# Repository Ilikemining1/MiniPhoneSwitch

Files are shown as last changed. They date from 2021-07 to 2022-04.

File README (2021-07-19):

The goal of this project is to build an analog phone switch supporting up to 8 stations and 2 analog trunks.  The switching itself is to be electromechanical in nature, but the control of the switching process and monitoring of lines will be controlled with a microcontroller.  This switch will be designed to be as modular as possible, as with the PCB manufacturing, it’s common to get multiple boards for your money, making it ideal that many of the boards are identical.

PCB Files are from KiCad, and simulation files are for LTSpice.

Simulation models are property of their respective companies.

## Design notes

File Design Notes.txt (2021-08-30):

Electronic Controlled Electromechanical Switch:
	Trunks:
		0-2 POTS trunk lines
		Programmable extension ringing
	Stations:
		0-8 Analog stations, each with programmable DNs.  
		DTMF and Pulse Support
		Properish full ring voltage, 90v RMS 20Hz Sine
	Tone Banks:
		2 tone banks, need at least one for each internal voice bus
		Produce call progress tones and decode DTMF
		Separate tone buses
	Internal Buses:
		2 internal voice paths, allowing for two simulaneous calls with any number of stations attached (multi-way calling)
		Can be used for internal calls or connected to a free analog trunk to place an outgoing call
		2 tone buses individually selectable.
	Electrical Parameters:
		Ring Generator:
			~1.2VA per 1 REN (13mA @ 90Vrms)
			Dividing active time can effectively triple REN capability of tranformer
			6 VA transformer: 5 REN no time division, effectively 15 REN with division
			Match amp wattage out approximately with transformer VA
			Transformer: FS28-200-C2 https://www.mouser.com/datasheet/2/410/FS28_200_C2-781258.pdf
			Amp: TPA3144D2 https://www.ti.com/lit/ds/symlink/tpa3144d2.pdf
		Station Cards:
			Gyrators to provide balaced line
			Ring / Voice Relay
			On-Station-Card Routing for modular design and cost savings
			Hook Detection:
				Optocoupler feeds schmitt trigger, uses software filtering to ignore ringing.
				Schmitt Trigger: NL17SZ14 https://www.mouser.com/datasheet/2/308/1/NL17SZ14_D-2318143.pdf
				Optocoupler: TCMD1000 https://www.mouser.com/datasheet/2/427/tcmd1000-1767230.pdf
			Gyrators:
				NPN: PHPT61003NY https://www.mouser.com/datasheet/2/916/PHPT61003NY-1320466.pdf
				PNP: PHPT61003PY https://www.mouser.com/datasheet/2/916/PHPT61003PY-1599682.pdf
			Connector: RJE0112001 https://cdn.amphenol-icc.com/media/wysiwyg/files/drawing/rje01x2001.pdf
			Switching Fabric:
				Relay options: EC2-5NU https://www.mouser.com/datasheet/2/212/1/KEM_R7002_EC2_EE2-1104574.pdf
				Relay Driver FET: XP231N02013R-G https://www.torexsemi.com/file/XP231N02013R/XP231N02013R.pdf
			Protection:
				Current Limit Zeners: BZX84-C9V1 https://www.mouser.com/datasheet/2/916/BZX84_SER-1319896.pdf
				Fuse (100mA slow blo): 0034.6605 https://www.mouser.com/datasheet/2/358/typ_MST_250-1888842.pdf
		Tone Banks:
			DTMF Decoder: MT8870 https://www.microsemi.com/document-portal/doc_view/127041-mt8870d-datasheet-oct2006
			Tone Generator:
				4 Wien Bridge Oscillators, 350Hz, 440Hz, 480Hz, and 620Hz
				74HC4316 to mix frequencies https://www.mouser.com/datasheet/2/916/74HC_HCT4316-1319536.pdf
				TL074, TL071 OP Amp https://www.ti.com/lit/ds/symlink/tl071h.pdf
		Microcontroller:
			Pin requirements:
				Trunks:
					2 Ring Sense (Input) (Interrupt)
					2 Hook Status (Input) (Interrupt)
					6 Trunk Routing (Output)
					2 Trunk Module Detect (Input)
				Stations:
					8 Ring Enable (Output)
					8 Hook Detect / Dial Pulse (Input) (Interrupt)
					24 Call Routing (Output)
					8 Station Module Detect (Input)
					1 Ring Gen Enable
				Tone Banks:
					8 DTMF Decoder Sense (Input)
					2 Digits Ready Sense (Input) (Interrupt)
					8 Tone Select (Output)
				Other:
					SPI:
						4 CS Pins (Output)
				Total: 32 Inputs (14 Interrupts), 51 Outputs, Total 83 GPIO
				This is an estimate and will likely change with time and the design.  
				IO Expanders: XRA1403IG24TR-F https://www.mouser.com/datasheet/2/146/XRA1403_100_092011-1889074.pdf
		Power Supply:
			-48v supply for battery voltage
			12v supply for everything else, used to produce 5v and 3.3v rails
			Additional dual +-5v for tone generator opamps
			PDME1-S12-D5-S https://www.mouser.com/datasheet/2/670/pdme1_s-1595987.pdf
			OKL-T/1-W12N-C https://www.mouser.com/datasheet/2/281/1/okl_t1_w12-1847213.pdf
			PMV65XP https://www.mouser.com/datasheet/2/916/PMV65XP-1600247.pdf

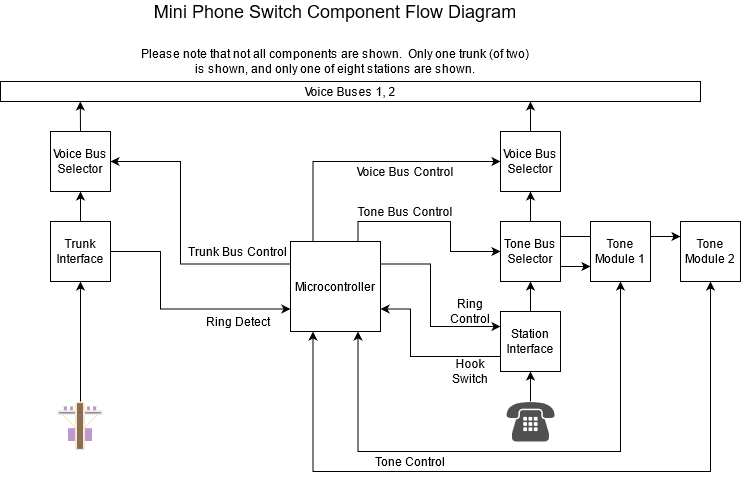
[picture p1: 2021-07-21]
Phone Switch.png

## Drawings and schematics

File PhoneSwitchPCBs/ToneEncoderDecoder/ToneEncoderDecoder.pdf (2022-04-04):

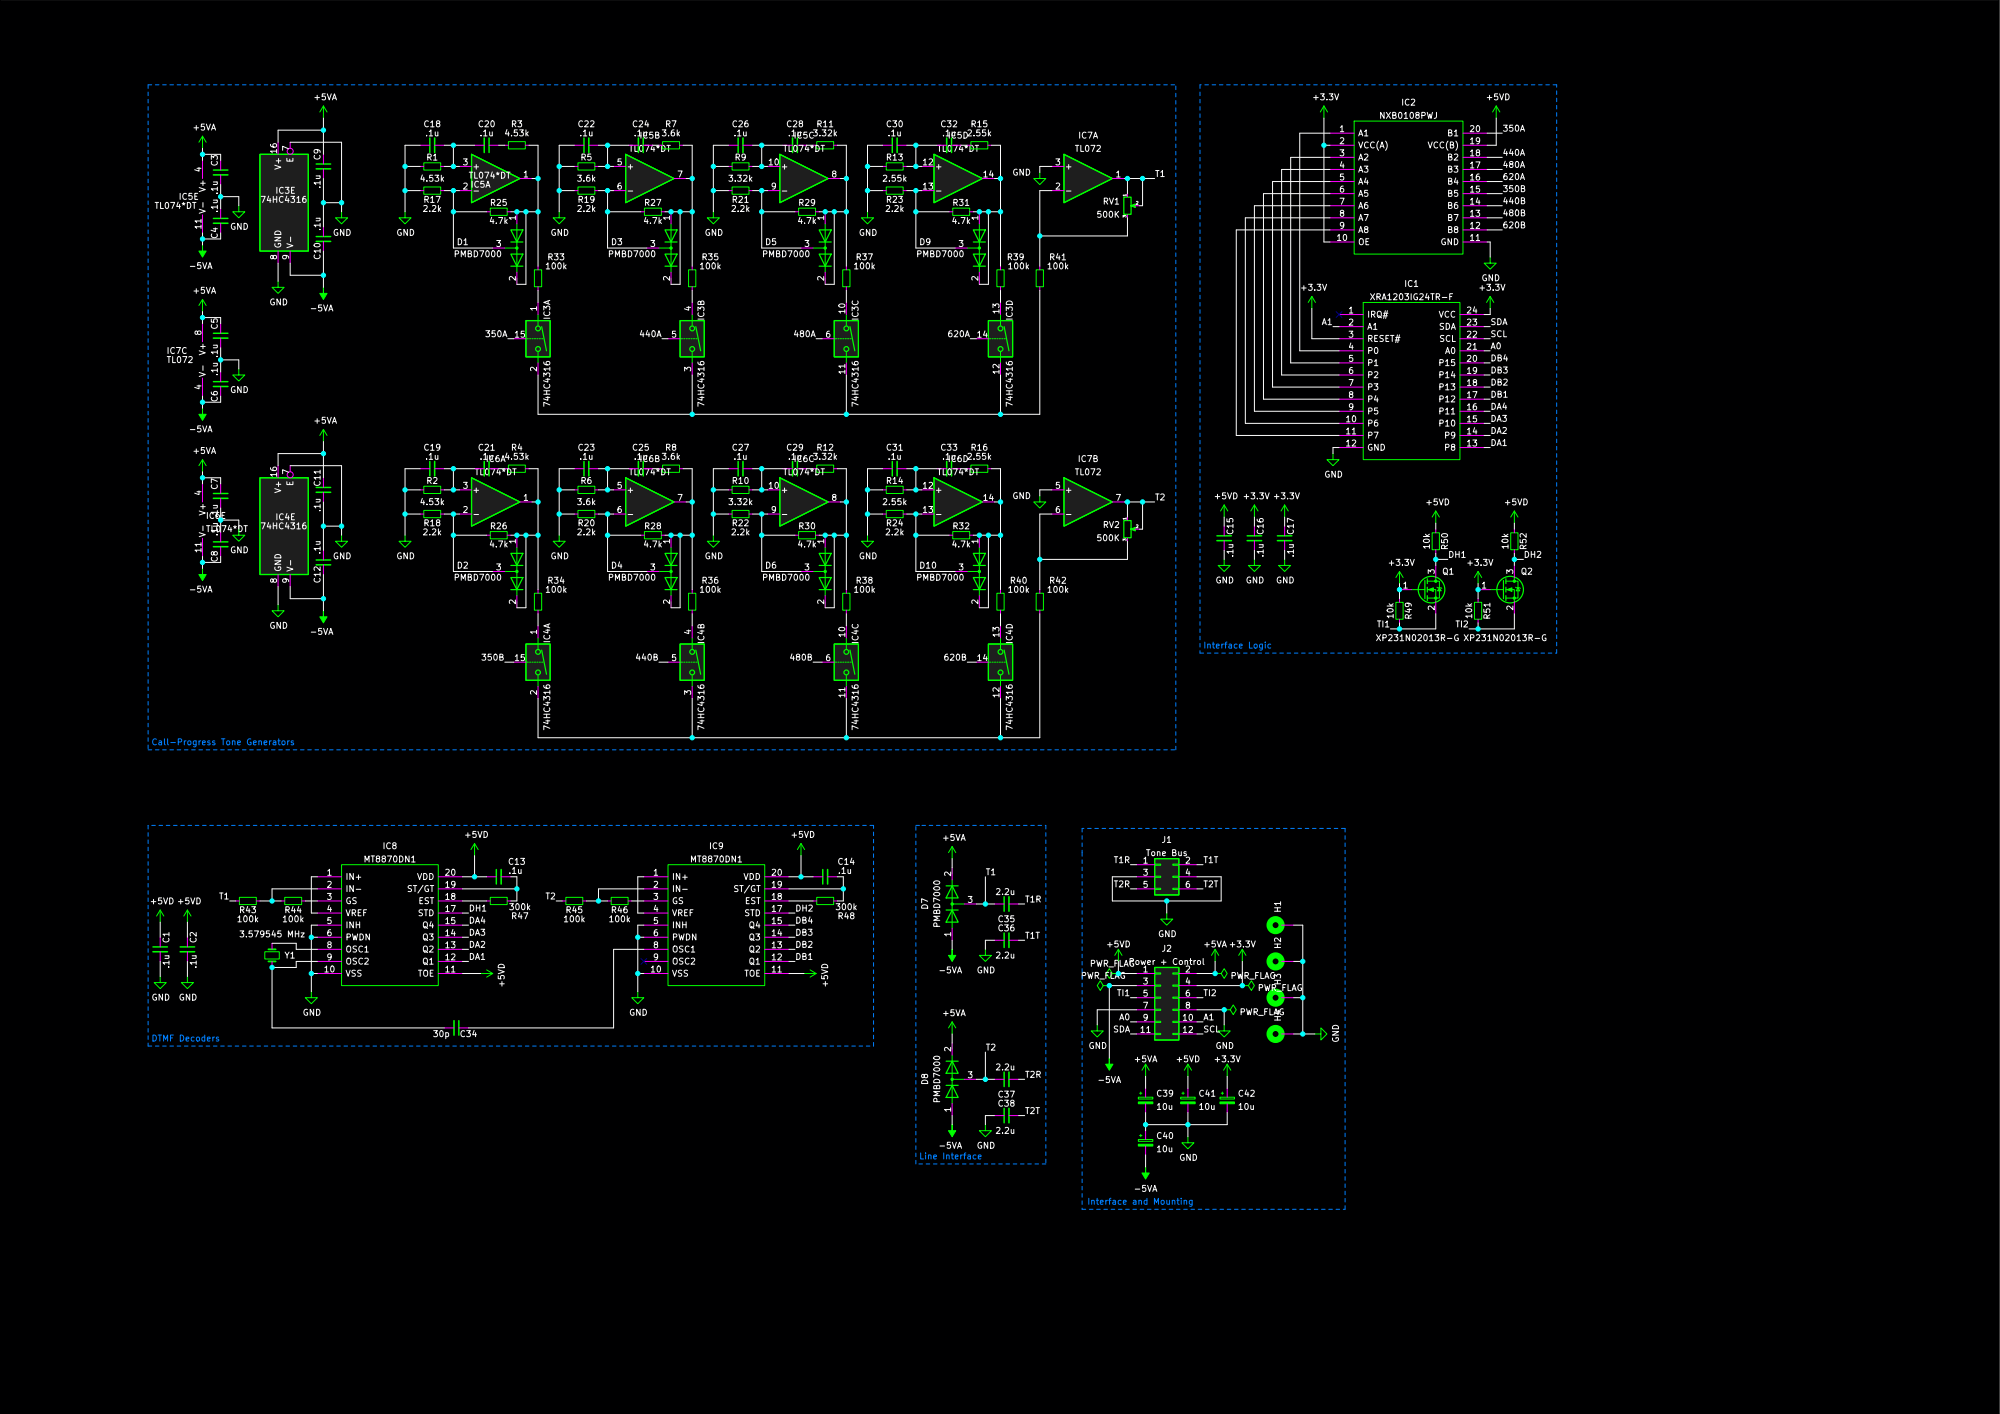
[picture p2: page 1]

Interface Logic DTMF Decoders

Line Interface Call-Progress Tone Generators

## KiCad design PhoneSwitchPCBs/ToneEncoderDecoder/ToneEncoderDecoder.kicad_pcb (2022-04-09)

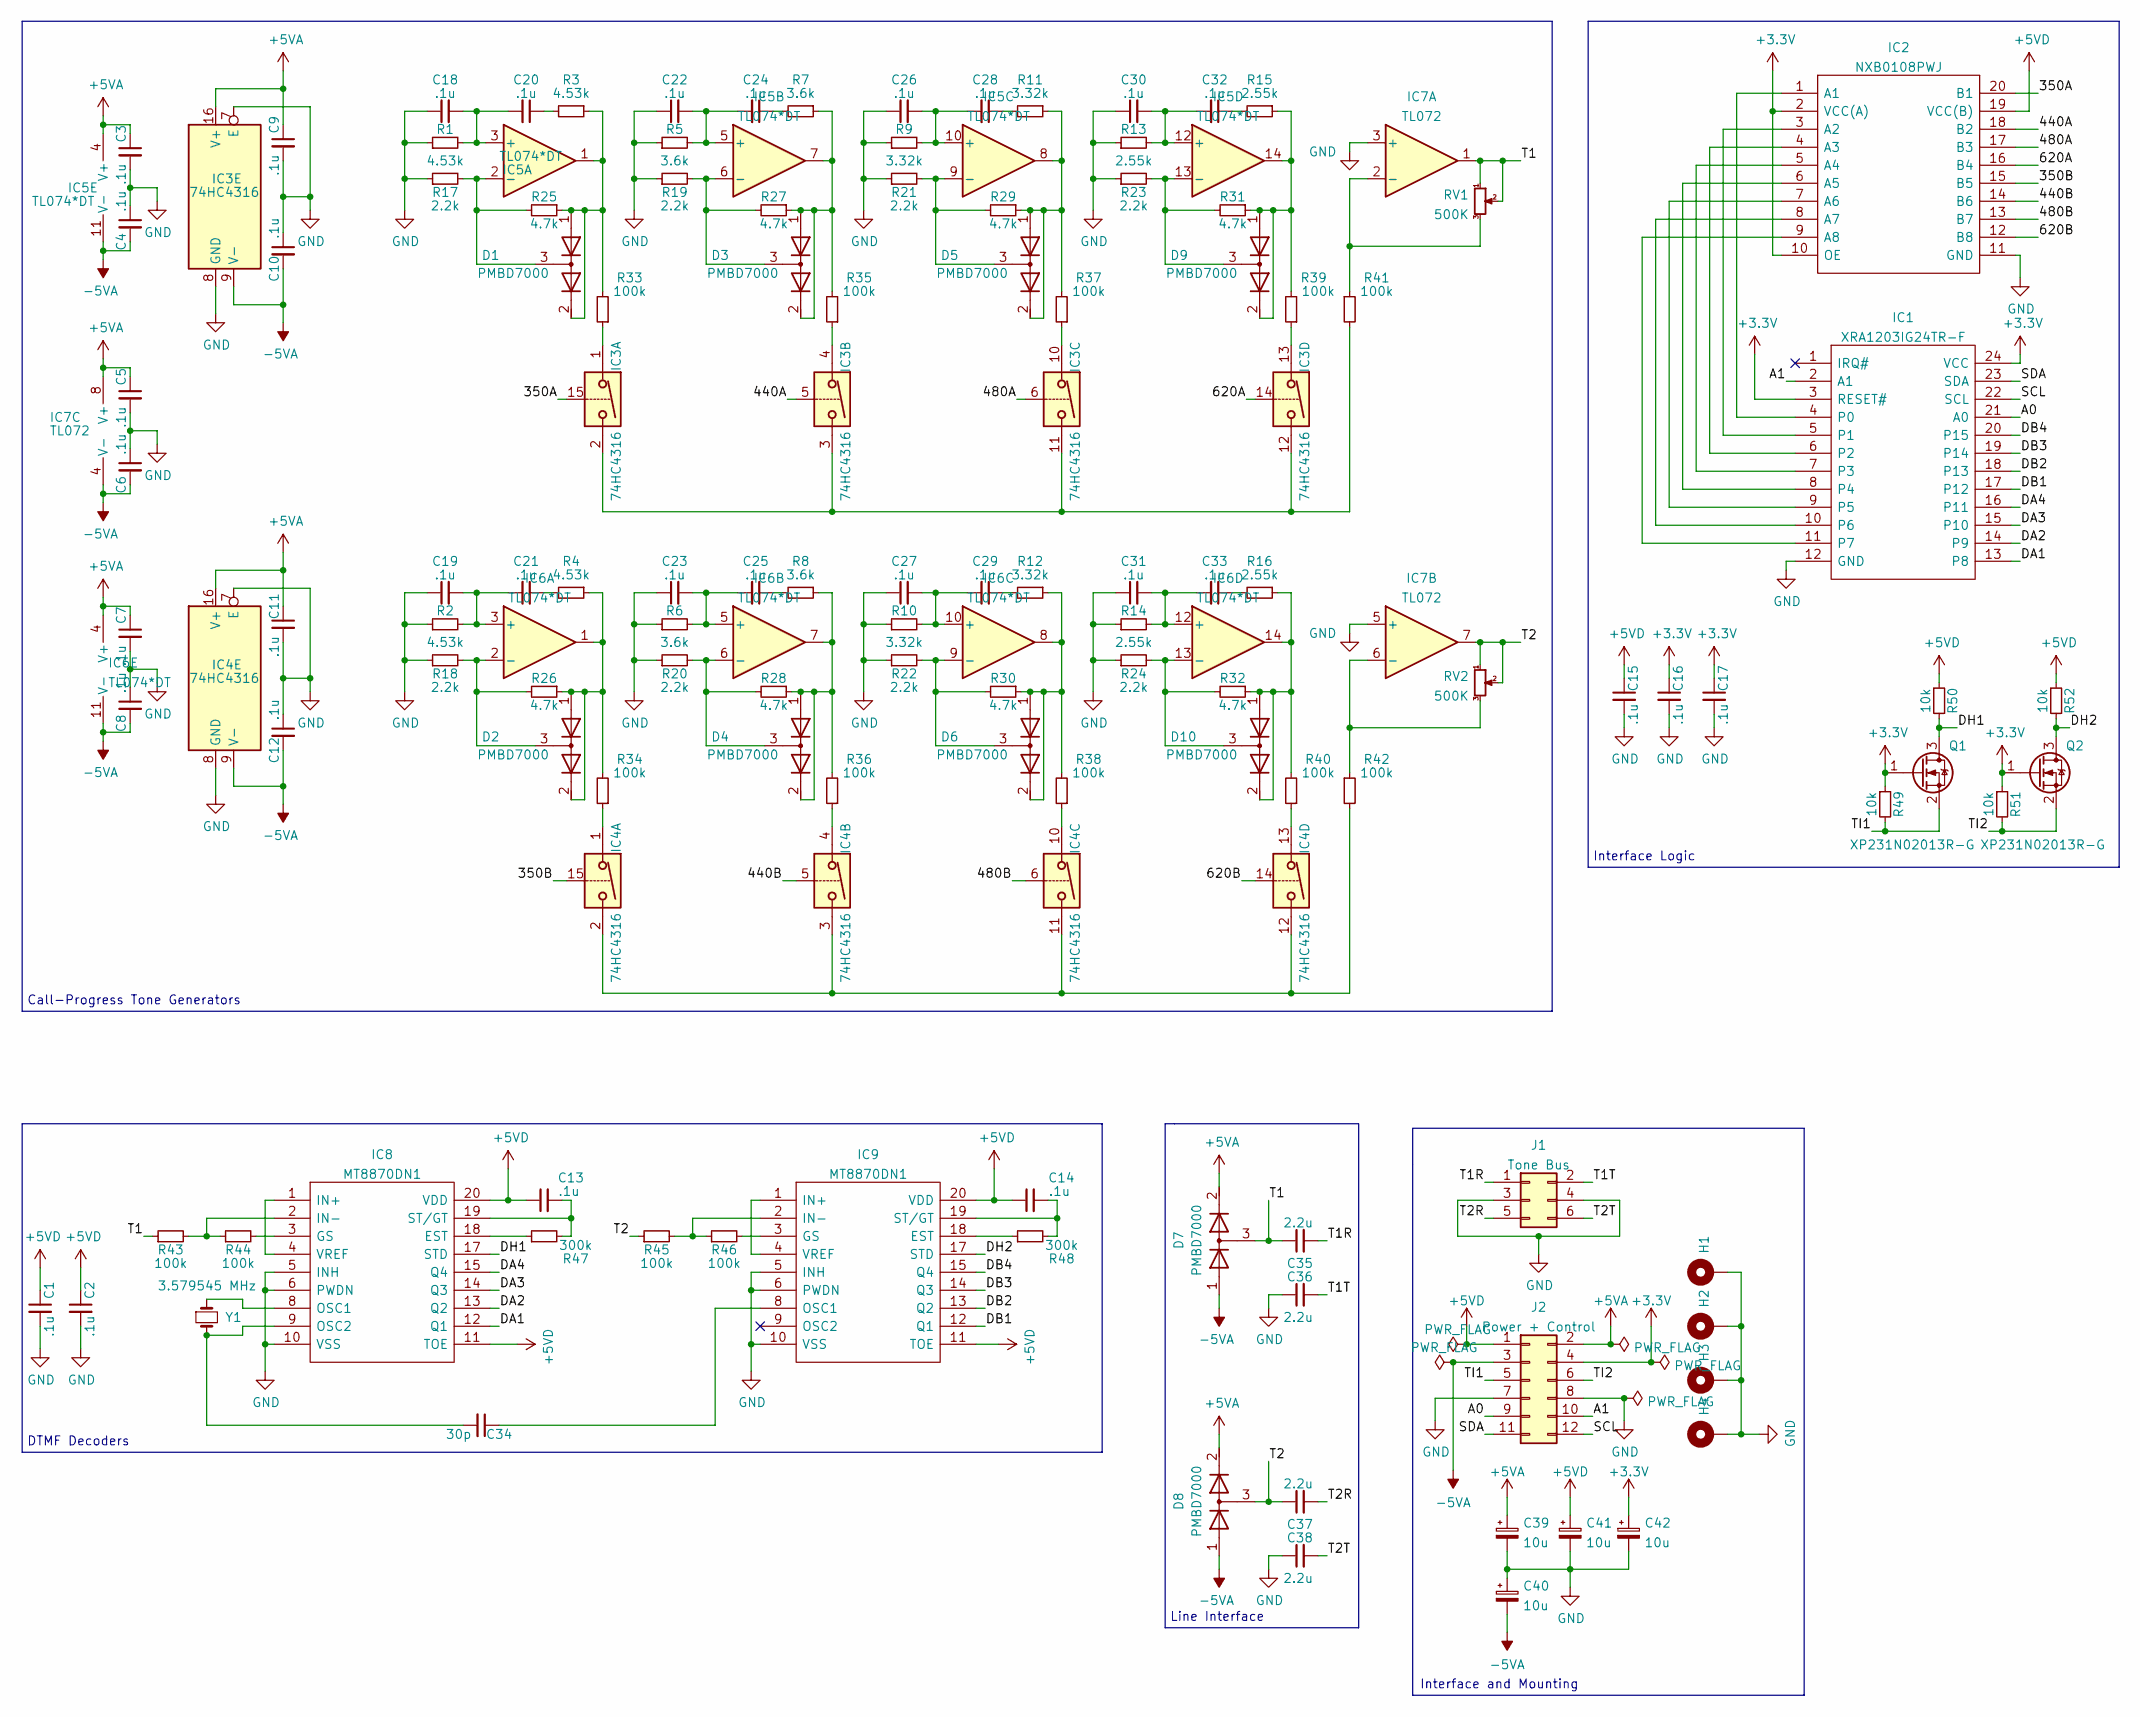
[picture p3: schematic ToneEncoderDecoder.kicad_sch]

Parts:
C1, C2, C3, C4, C5, C6, C7, C8, C9, C10, C11, C12, C13, C14, C15, C16, C17: .1u; C_0603_1608Metric_Pad1.08x0.95mm_HandSolder
C18, C19, C20, C21, C22, C23, C24, C25, C26, C27, C28, C29, C30, C31, C32, C33: .1u; C_1206_3216Metric_Pad1.33x1.80mm_HandSolder
C34: 30p; C_0603_1608Metric_Pad1.08x0.95mm_HandSolder
C35, C36, C37, C38: 2.2u; C_Radial_D5.0mm_H11.0mm_P2.00mm
C39, C40, C41, C42: 10u; C_0805_2012Metric_Pad1.18x1.45mm_HandSolder
D1, D2, D3, D4, D5, D6, D7, D8, D9, D10: PMBD7000; SOT-23
H1, H2, H3, H4: M3; MountingHole_3.2mm_M3_Pad
IC1: XRA1203IG24TR-F; TSSOP-24_4.4x7.8mm_P0.65mm
IC2: NXB0108PWJ; TSSOP-20_4.4x6.5mm_P0.65mm
IC3, IC4: 74HC4316; TSSOP-16_4.4x5mm_P0.65mm
IC5, IC6: TL074*DT; SOIC-14_3.9x8.7mm_P1.27mm
IC7: TL072; SOIC-8_3.9x4.9mm_P1.27mm
IC8, IC9: MT8870DN1; SSOP-20_5.3x7.2mm_P0.65mm
J1: Tone Bus; PinHeader_2x03_P2.54mm_Vertical
J2: Power + Control; PinHeader_2x06_P2.54mm_Vertical
Q1, Q2: XP231N02013R-G; SOT-323_SC-70_Handsoldering
R1, R2, R3, R4: 4.53k; R_0603_1608Metric_Pad0.98x0.95mm_HandSolder
R5, R6, R7, R8: 3.6k; R_0603_1608Metric_Pad0.98x0.95mm_HandSolder
R9, R10, R11, R12: 3.32k; R_0603_1608Metric_Pad0.98x0.95mm_HandSolder
R13, R14, R15, R16: 2.55k; R_0603_1608Metric_Pad0.98x0.95mm_HandSolder
R17, R18, R19, R20, R21, R22, R23, R24: 2.2k; R_0603_1608Metric_Pad0.98x0.95mm_HandSolder
R25, R26, R27, R28, R29, R30, R31, R32: 4.7k; R_0603_1608Metric_Pad0.98x0.95mm_HandSolder
R33, R34, R35, R36, R37, R38, R39, R40, R41, R42, R43, R44, R45, R46: 100k; R_0603_1608Metric_Pad0.98x0.95mm_HandSolder
R47, R48: 300k; R_0603_1608Metric_Pad0.98x0.95mm_HandSolder
R49, R50, R51, R52: 10k; R_0603_1608Metric_Pad0.98x0.95mm_HandSolder
RV1, RV2: 500K; Potentiometer_Bourns_3296W_Vertical
Y1: 3.579545 MHz; Crystal_SMD_HC49-SD_HandSoldering

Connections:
+3V3: C16.1, C17.1, C42.1, IC1.3 (RESET#), IC1.24 (VCC), IC2.2 (VCC(A)), IC2.10 (OE), J2.4, Q1.1 (G), Q2.1 (G), R49.1, R51.1
+5VA: C3.1, C5.1, C7.1, C9.1, C11.1, C39.1, D7.2 (K2), D8.2 (K2), IC3.16 (V+), IC4.16 (V+), IC5.4 (V+), IC6.4 (V+), IC7.8 (V+), J2.2
+5VD: C1.1, C2.1, C13.1, C14.1, C15.1, C41.1, IC2.19 (VCC(B)), IC8.11 (TOE), IC8.20 (VDD), IC9.11 (TOE), IC9.20 (VDD), J2.1, R50.1, R52.1
-5VA: C4.2, C6.2, C8.2, C10.2, C12.2, C40.2, D7.1 (A1), D8.1 (A1), IC3.9 (V-), IC4.9 (V-), IC5.11 (V-), IC6.11 (V-), IC7.4 (V-), J2.3
/350A: IC2.20 (B1), IC3.15
/350B: IC2.15 (B5), IC4.15
/440A: IC2.18 (B2), IC3.5
/440B: IC2.14 (B6), IC4.5
/480A: IC2.17 (B3), IC3.6
/480B: IC2.13 (B7), IC4.6
/620A: IC2.16 (B4), IC3.14
/620B: IC2.12 (B8), IC4.14
/A0: IC1.21 (A0), J2.9
/A1: IC1.2 (A1), J2.10
/DA1: IC1.13 (P8), IC8.12 (Q1)
/DA2: IC1.14 (P9), IC8.13 (Q2)
/DA3: IC1.15 (P10), IC8.14 (Q3)
/DA4: IC1.16 (P11), IC8.15 (Q4)
/DB1: IC1.17 (P12), IC9.12 (Q1)
/DB2: IC1.18 (P13), IC9.13 (Q2)
/DB3: IC1.19 (P14), IC9.14 (Q3)
/DB4: IC1.20 (P15), IC9.15 (Q4)
/DH1: IC8.17 (STD), Q1.3 (D), R50.2
/DH2: IC9.17 (STD), Q2.3 (D), R52.2
/SCL: IC1.22 (SCL), J2.12
/SDA: IC1.23 (SDA), J2.11
/T1: C35.1, D7.3 (K1A2), IC7.1, R43.1, RV1.1, RV1.2
/T1R: C35.2, J1.1
/T1T: C36.2, J1.2
/T2: C37.1, D8.3 (K1A2), IC7.7, R45.1, RV2.1, RV2.2
/T2R: C37.2, J1.5
/T2T: C38.2, J1.6
/TI1: J2.5, Q1.2 (S), R49.2
/TI2: J2.6, Q2.2 (S), R51.2
GND: C1.2, C2.2, C3.2, C4.1, C5.2, C6.1, C7.2, C8.1, C9.2, C10.1, C11.2, C12.1, C15.2, C16.2, C17.2, C18.1, C19.1, C22.1, C23.1, C26.1, C27.1, C30.1, C31.1, C36.1, C38.1, C39.2, C40.1, C41.2, C42.2, H1.1, H2.1, H3.1, H4.1, IC1.12 (GND), IC2.11 (GND), IC3.7 (E), IC3.8 (GND), IC4.7 (E), IC4.8 (GND), IC7.3 (+), IC7.5 (+), IC8.5 (INH), IC8.6 (PWDN), IC8.10 (VSS), IC9.5 (INH), IC9.6 (PWDN), IC9.10 (VSS), J1.3, J1.4, J2.7, J2.8, R1.1, R2.1, R5.1, R6.1, R9.1, R10.1, R13.1, R14.1, R17.1, R18.1, R19.1, R20.1, R21.1, R22.1, R23.1, R24.1
unnamed: C13.2, IC8.19 (ST/GT), R47.2
unnamed: C14.2, IC9.19 (ST/GT), R48.2
unnamed: C18.2, C20.2, IC5.3 (+), R1.2
unnamed: C19.2, C21.2, IC6.3 (+), R2.2
unnamed: C20.1, R3.2
unnamed: C21.1, R4.2
unnamed: C22.2, C24.2, IC5.5 (+), R5.2
unnamed: C23.2, C25.2, IC6.5 (+), R6.2
unnamed: C24.1, R7.2
unnamed: C25.1, R8.2
unnamed: C26.2, C28.2, IC5.10 (+), R9.2
unnamed: C27.2, C29.2, IC6.10 (+), R10.2
unnamed: C28.1, R11.2
unnamed: C29.1, R12.2
unnamed: C30.2, C32.2, IC5.12 (+), R13.2
unnamed: C31.2, C33.2, IC6.12 (+), R14.2
unnamed: C32.1, R15.2
unnamed: C33.1, R16.2
unnamed: C34.1, IC9.8 (OSC1)
unnamed: C34.2, IC8.9 (OSC2), Y1.2
unnamed: D1.1 (A1), D1.2 (K2), IC5.1, R3.1, R25.1, R33.2
unnamed: D1.3 (K1A2), IC5.2 (-), R17.2, R25.2
unnamed: D2.1 (A1), D2.2 (K2), IC6.1, R4.1, R26.1, R34.2
unnamed: D2.3 (K1A2), IC6.2 (-), R18.2, R26.2
unnamed: D3.1 (A1), D3.2 (K2), IC5.7, R7.1, R27.1, R35.2
unnamed: D3.3 (K1A2), IC5.6 (-), R19.2, R27.2
unnamed: D4.1 (A1), D4.2 (K2), IC6.7, R8.1, R28.1, R36.2
unnamed: D4.3 (K1A2), IC6.6 (-), R20.2, R28.2
unnamed: D5.1 (A1), D5.2 (K2), IC5.8, R11.1, R29.1, R37.2
unnamed: D5.3 (K1A2), IC5.9 (-), R21.2, R29.2
unnamed: D6.1 (A1), D6.2 (K2), IC6.8, R12.1, R30.1, R38.2
unnamed: D6.3 (K1A2), IC6.9 (-), R22.2, R30.2
unnamed: D9.1 (A1), D9.2 (K2), IC5.14, R15.1, R31.1, R39.2
unnamed: D9.3 (K1A2), IC5.13 (-), R23.2, R31.2
unnamed: D10.1 (A1), D10.2 (K2), IC6.14, R16.1, R32.1, R40.2
unnamed: D10.3 (K1A2), IC6.13 (-), R24.2, R32.2
unnamed: IC1.4 (P0), IC2.1 (A1)
unnamed: IC1.5 (P1), IC2.3 (A2)
unnamed: IC1.6 (P2), IC2.4 (A3)
unnamed: IC1.7 (P3), IC2.5 (A4)
unnamed: IC1.8 (P4), IC2.6 (A5)
unnamed: IC1.9 (P5), IC2.7 (A6)
unnamed: IC1.10 (P6), IC2.8 (A7)
unnamed: IC1.11 (P7), IC2.9 (A8)
unnamed: IC3.1, R33.1
unnamed: IC3.4, R35.1
unnamed: IC3.10, R37.1
unnamed: IC3.2, IC3.3, IC3.11, IC3.12, R41.2
unnamed: IC3.13, R39.1
unnamed: IC4.1, R34.1
unnamed: IC4.4, R36.1
unnamed: IC4.10, R38.1
unnamed: IC4.2, IC4.3, IC4.11, IC4.12, R42.2
unnamed: IC4.13, R40.1
unnamed: IC7.2 (-), R41.1, RV1.3
unnamed: IC7.6 (-), R42.1, RV2.3
unnamed: IC8.1 (IN+), IC8.4 (VREF)
unnamed: IC8.2 (IN-), R43.2, R44.1
unnamed: IC8.3 (GS), R44.2
unnamed: IC8.8 (OSC1), Y1.1
unnamed: IC8.18 (EST), R47.1
unnamed: IC9.1 (IN+), IC9.4 (VREF)
unnamed: IC9.2 (IN-), R45.2, R46.1
unnamed: IC9.3 (GS), R46.2
unnamed: IC9.18 (EST), R48.1

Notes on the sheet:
Line Interface
Interface Logic
DTMF Decoders
Interface and Mounting
Call-Progress Tone Generators

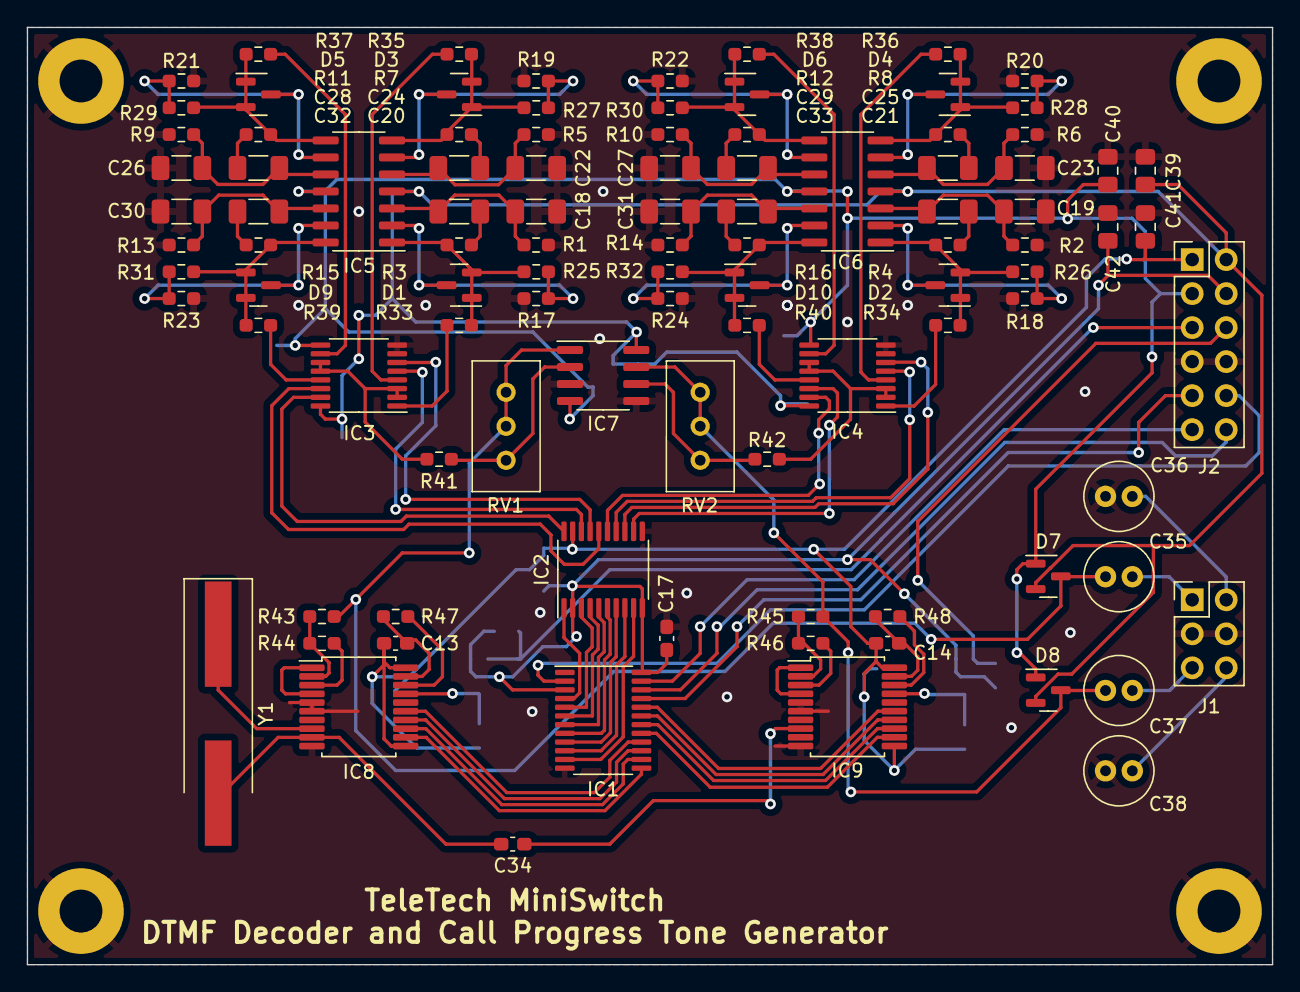
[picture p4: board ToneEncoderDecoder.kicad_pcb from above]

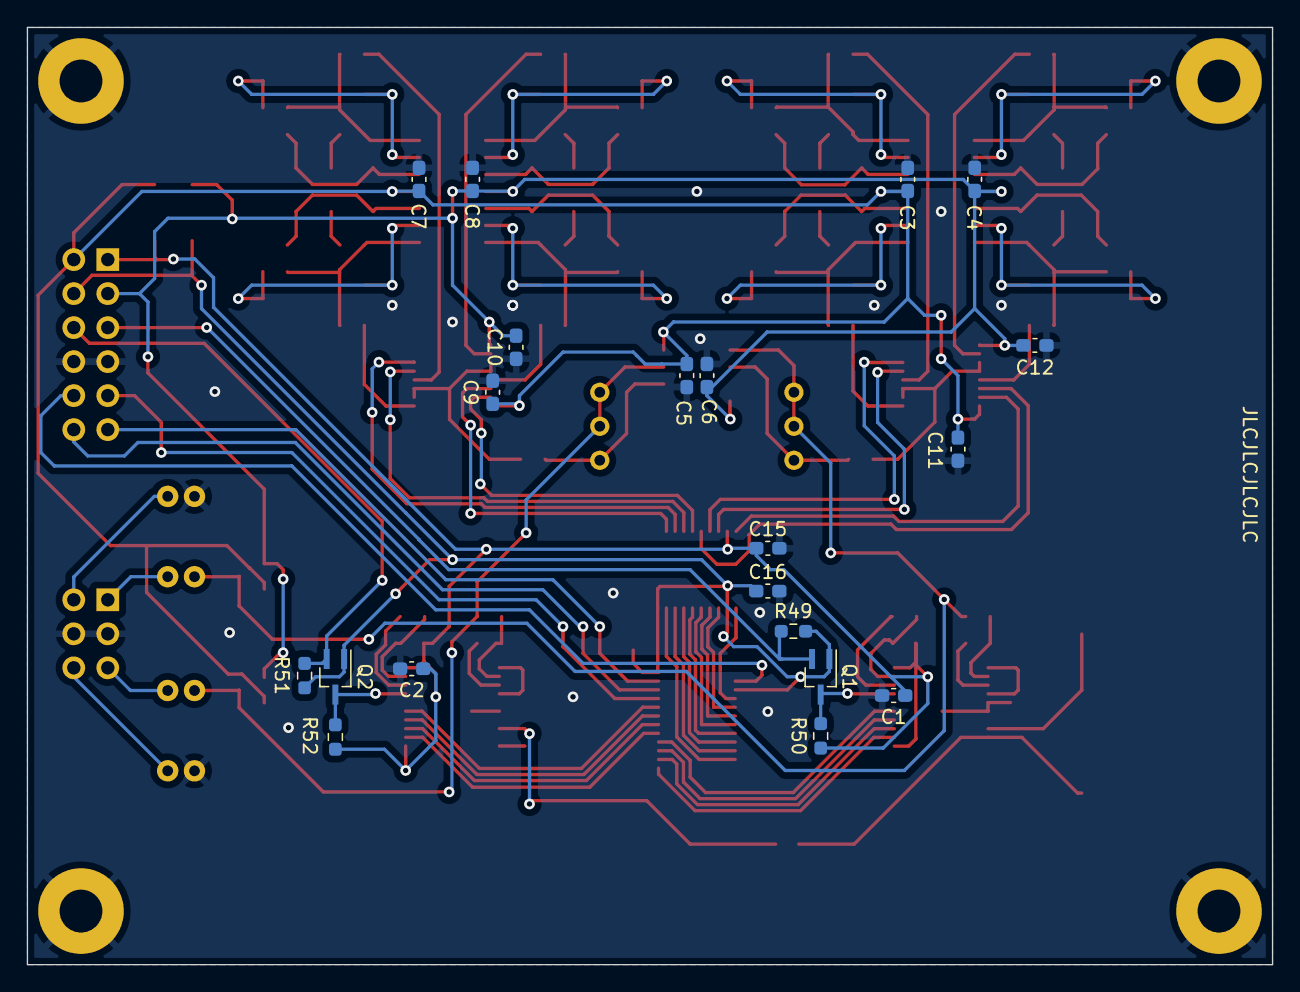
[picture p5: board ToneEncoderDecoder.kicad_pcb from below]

Board: 2 copper layers, 93.0 x 70.0 mm, 124 parts (20 on the bottom side), 100 nets.

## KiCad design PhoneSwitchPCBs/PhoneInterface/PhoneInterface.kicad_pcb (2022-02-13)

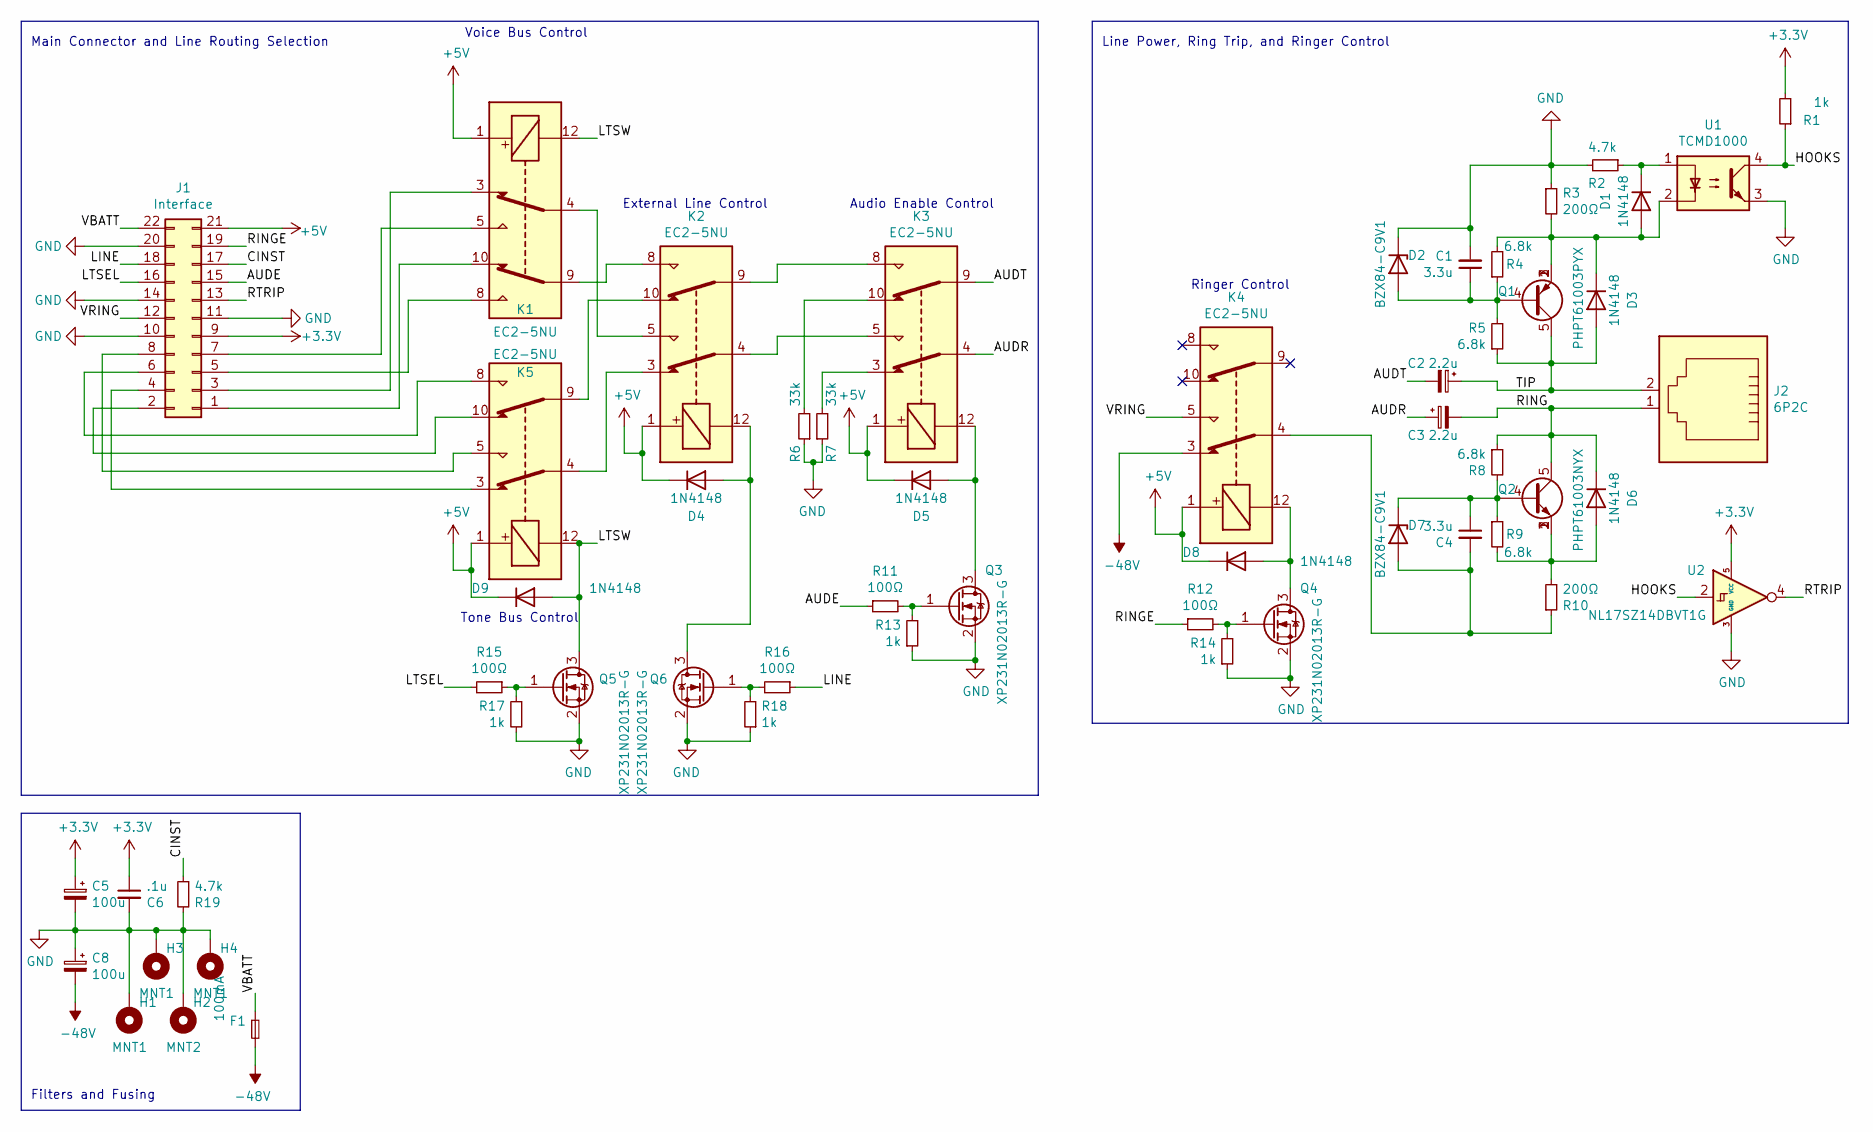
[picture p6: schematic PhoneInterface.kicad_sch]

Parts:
C1, C4: 3.3u; CP_Radial_D5.0mm_P2.00mm
C2, C3: 2.2u; CP_Radial_D4.0mm_P1.50mm
C5: 100u; CP_Radial_D5.0mm_P2.00mm
C6: .1u; C_0603_1608Metric_Pad1.08x0.95mm_HandSolder
C8: 100u; CP_Radial_D10.0mm_P5.00mm
D1, D3, D4, D5, D6, D8, D9: 1N4148; D_DO-35_SOD27_P7.62mm_Horizontal
D2, D7: BZX84-C9V1; D_SOT-23_ANK
F1: 100mA; 00346605
H1, H3, H4: MNT1; MountingHole_2.7mm_M2.5_Pad
H2: MNT2; MountingHole_2.7mm_M2.5_Pad
J1: Interface; PinHeader_2x11_P2.54mm_Vertical
J2: 6P2C; RJE0112001
K1, K2, K3, K4, K5: EC2-5NU; Relay_DPDT_Kemet_EC2
Q1: PHPT61003PYX; LFPAK56
Q2: PHPT61003NYX; LFPAK56
Q3, Q4, Q5, Q6: XP231N02013R-G; SOT-323_SC-70_Handsoldering
R1, R13, R14, R17, R18: 1k; R_0805_2012Metric_Pad1.20x1.40mm_HandSolder
R2, R19: 4.7k; R_0805_2012Metric_Pad1.20x1.40mm_HandSolder
R3, R10: 200Ω; R_Axial_DIN0516_L15.5mm_D5.0mm_P20.32mm_Horizontal
R4, R5, R8, R9: 6.8k; R_1210_3225Metric_Pad1.30x2.65mm_HandSolder
R6, R7: 33k; R_0805_2012Metric_Pad1.20x1.40mm_HandSolder
R11, R12, R15, R16: 100Ω; R_0805_2012Metric_Pad1.20x1.40mm_HandSolder
U1: TCMD1000; SOP-4_4.4x2.6mm_P1.27mm
U2: NL17SZ14DBVT1G; SOT-23-5

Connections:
+3V3: C5.1, C6.1, J1.9, R1.2, U2.5 (VCC)
+5V: D4.1 (K), D5.1 (K), D8.1 (K), D9.1 (K), J1.21, K1.1, K2.1, K3.1, K4.1, K5.1; also elsewhere on the board
-48V: C8.2, F1.2, K4.3
/AUDE: J1.15, R11.1
/AUDR: C3.1, K3.4; also elsewhere on the board
/AUDT: C2.2, K3.9; also elsewhere on the board
/CINST: J1.17, R19.1
/HOOKS: R1.1, U1.4, U2.2
/LINE: J1.18, R16.1
/LTSEL: J1.16, R15.2
/LTSW: D9.2 (A), K1.12, K5.12, Q5.3 (D)
/RING: C3.2, D6.1 (K), J2.1, Q2.5 (C), R8.1
/RINGE: J1.19, R12.1
/RTRIP: J1.13, U2.4
/TIP: C2.1, D3.2 (A), J2.2, Q1.5 (C), R5.1
/VBATT: F1.1, J1.22
/VRING: J1.12, K4.5
GND: C1.2, C5.2, C6.2, C8.1, D2.1 (K), H1.1, H2.1, H3.1, H4.1, J1.10, J1.11, J1.14, J1.20, Q3.2 (S), Q4.2 (S), Q5.2 (S), Q6.2 (S), R2.2, R3.1, R6.1, R7.1, R13.1, R14.1, R17.2, R18.1, R19.2, U1.3, U2.3 (GND)
unnamed: C1.1, D2.2 (A), Q1.4 (B), R4.1, R5.2
unnamed: C4.1, D7.1 (K), Q2.4 (B), R8.2, R9.1
unnamed: C4.2, D7.2 (A), K4.4, R10.1
unnamed: D1.1 (K), R2.1, U1.1
unnamed: D1.2 (A), D3.1 (K), Q1.1 (E), Q1.2 (E), Q1.3 (E), R3.2, R4.2, U1.2
unnamed: D4.2 (A), K2.12, Q6.3 (D)
unnamed 24: D5.2 (A), K3.12, Q3.3 (D); also elsewhere on the board
unnamed: D6.2 (A), Q2.1 (E), Q2.2 (E), Q2.3 (E), R9.2, R10.2
unnamed: D8.2 (A), K4.12, Q4.3 (D)
unnamed: J1.1, K1.10
unnamed: J1.2, K5.10
unnamed: J1.3, K1.3
unnamed: J1.4, K5.3
unnamed: J1.5, K1.8
unnamed: J1.6, K5.8
unnamed: J1.7, K1.5
unnamed: J1.8, K5.5
unnamed: K1.4, K2.5
unnamed: K1.9, K2.8
unnamed: K2.3, K5.4
unnamed 38: K2.4, K3.5; also elsewhere on the board
unnamed 39: K2.9, K3.8; also elsewhere on the board
unnamed: K2.10, K5.9
unnamed 41: K3.3, R7.2; also elsewhere on the board
unnamed 42: K3.10, R6.2; also elsewhere on the board
unnamed: Q3.1 (G), R11.2, R13.2
unnamed: Q4.1 (G), R12.2, R14.2
unnamed: Q5.1 (G), R15.1, R17.1
unnamed: Q6.1 (G), R16.2, R18.2

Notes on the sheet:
Ringer Control
Main Connector and Line Routing Selection
External Line Control
Filters and Fusing
Voice Bus Control
Line Power, Ring Trip, and Ringer Control
Tone Bus Control
Audio Enable Control

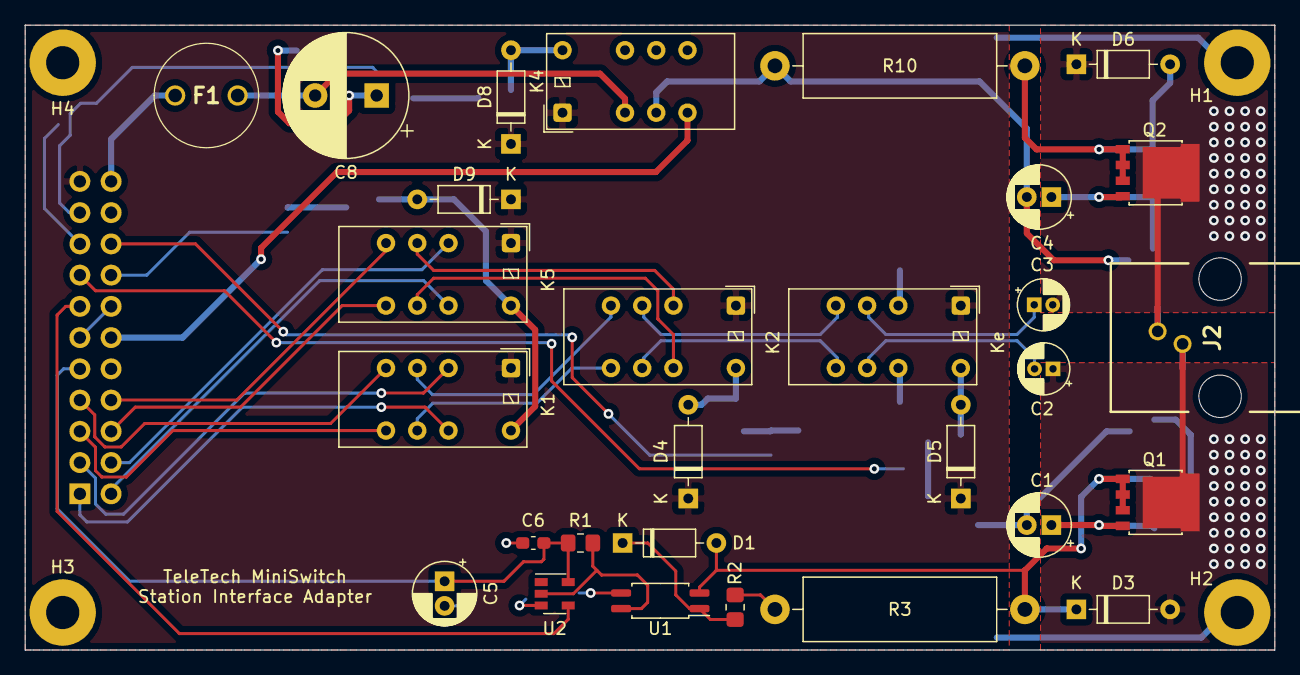
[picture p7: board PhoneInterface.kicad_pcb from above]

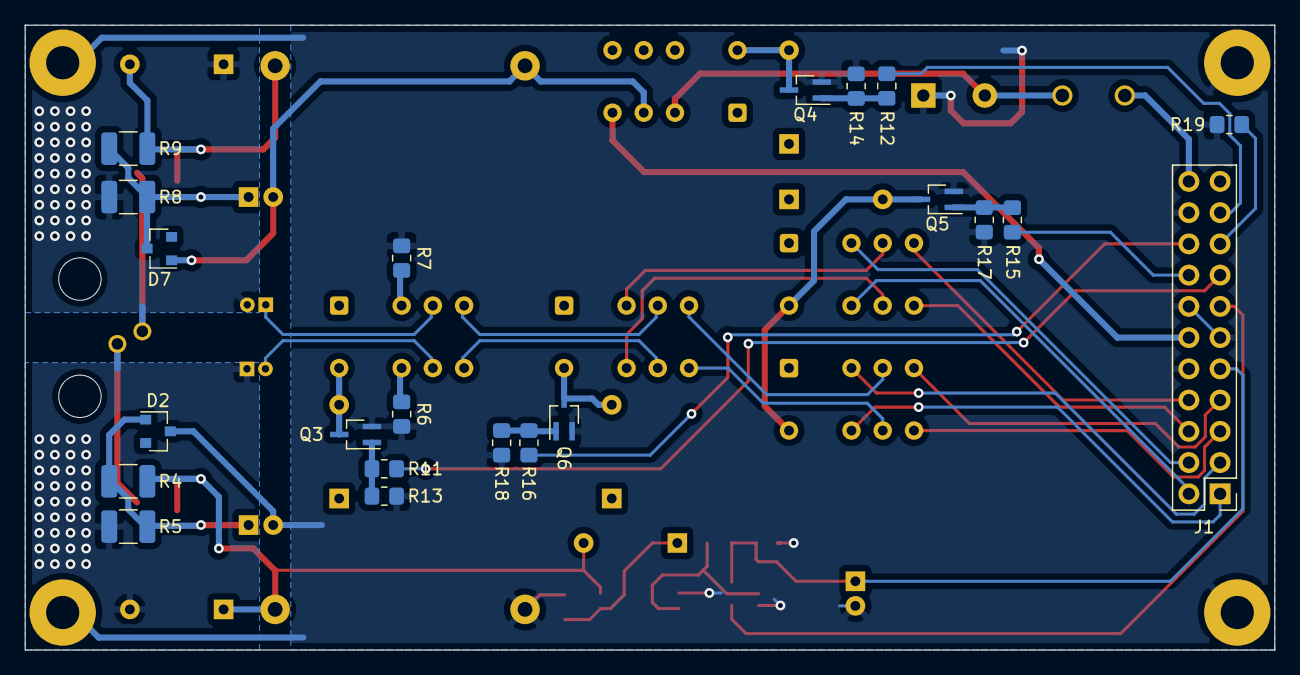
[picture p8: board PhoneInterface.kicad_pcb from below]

Board: 2 copper layers, 101.6 x 50.8 mm, 55 parts (22 on the bottom side), 47 nets.

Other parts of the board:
Ke: EC2-5NU; Relay_DPDT_Kemet_EC2

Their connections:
+5V: Ke.1; also elsewhere on the board
/AUDR: Ke.4; also elsewhere on the board
/AUDT: Ke.9; also elsewhere on the board
unnamed 24: Ke.12; also elsewhere on the board
unnamed 38: Ke.5; also elsewhere on the board
unnamed 39: Ke.8; also elsewhere on the board
unnamed 41: Ke.3; also elsewhere on the board
unnamed 42: Ke.10; also elsewhere on the board

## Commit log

2021-07-19 Initial commit, start using version control
    Initial commit on the MiniPhoneSwitch project, including current schematics, notes, and simulation designs / models.
    [PhoneInterface.sch]
2021-07-20 Update notes based on changing plans, minor changes to schematics and sim files
    [PhoneInterface.sch]
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2021-07-22 Updated schematics and notes
    Changed pin count for using analog switch bypass of ring cut filter, worked more on schematics, including deciding to put routing on line modules.
    [PhoneInterface.sch]
2021-07-22 Update notes and progress on schematics
    Further work on station card schematics, changed some things in notes.
    [PhoneInterface.sch]
2021-07-22 Continued work on schematic
    [PhoneInterface.sch]
2021-07-23 Continue work on schematic and add more notes
    [PhoneInterface.sch]
2021-07-24 Progress on schematic, switch to using software filtering
    Clean up notes regarding only needing a single Schmitt trigger for software-based filtering of ring trip. Remove the unneeded switch IC from notes as well as the schematic, and remove the filter.
    [PhoneInterface.sch]
2021-07-24 Update notes, change schematic to use 3.3 volt IO in addition to more progress
    [PhoneInterface.sch]
2021-07-24 Finalize non-interchangeable station/trunk modules, mostly finish schematic
    [PhoneInterface.sch]
2021-07-24 Minor schematic touchups, removed unneeded project file, add PDF schematic
    [PhoneInterface.sch]
2021-07-24 Added current limit functionality, simplified voice/tone relay logic
    [PhoneInterface.sch]
2021-07-24 Fixed reversed PNP polarity
    [PhoneInterface.sch]
2021-07-25 Update Notes, create custom footprint for RJ11 connector, associate footprints, fix cap types
    [PhoneInterface.sch]
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2021-07-25 Use ugly hack to add the extra emitter pins on the power transistors, generate netlist
    [PhoneInterface.sch]
2021-07-25 Start initial PCB layout, fix some small mistakes in schematic
    [PhoneInterface.kicad_pcb, PhoneInterface.sch]
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2021-07-25 More progress to PCB Layout
    [PhoneInterface.kicad_pcb]
2021-07-26 Mostly finish trace routing.
    [PhoneInterface.kicad_pcb]
2021-07-26 tweaked detect resistor to pulldown, finished routing all tracks!
    [PhoneInterface.kicad_pcb, PhoneInterface.sch]
2021-07-26 Remove extra cap from schematic, finish up PCB design
    [PhoneInterface.kicad_pcb, PhoneInterface.sch]
2021-07-26 Minor tweaks before PCB attempt 2
    [PhoneInterface.sch]
2021-07-26 Rename OLD PCB layout, remove unneeded netlist, update schematic PDF
    [PhoneInterfaceOLD.kicad_pcb]
2021-07-26 Start NEW more carefully laid out PCB. Completed gyrator sections.
    [PhoneInterface.kicad_pcb]
2021-07-26 More progress, added two extra mounting holes
    [PhoneInterface.kicad_pcb, PhoneInterface.sch]
2021-07-27 Tweaked schematic to make routing easier
    [PhoneInterface.sch]
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2021-07-27 Finalize PCB, move around silkscreen markings
    [PhoneInterface.kicad_pcb]
2021-07-27 Fixed a minor issue with the silkscreen
    [PhoneInterface.kicad_pcb]
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2021-08-04 Updated gerbers, added zip, added relay 3d model
    [PhoneInterface-B_CrtYd.gbr, PhoneInterface-B_Cu.gbr, PhoneInterface-B_Mask.gbr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]
2021-08-19 Delete PhoneInterfaceOLD.kicad_pcb
    Remove old PCB design
    [PhoneInterfaceOLD.kicad_pcb]
2021-08-23 Started on Switch Backplane schematic, updated notes on tone generation and power supplies
    [SwitchBackplane.kicad_pcb, SwitchBackplane.sch]
2021-08-23 Continue work on backplane schematic
    [SwitchBackplane.sch]
2021-08-23 Added simulation of tone generators, updated backplane schematic
    [SwitchBackplane.sch]
2021-08-25 Continued work on backplane schematic
    [SwitchBackplane.sch]
2021-08-26 Add station interface ports, initial power supply design
    [SwitchBackplane.sch]
2021-08-26 Update notes on ring generator and continued schematic work
    [SwitchBackplane.sch]
2021-08-27 Continued backplane schematic work
    [SwitchBackplane.sch]
2021-08-27 Added ring generator oscillator spice sim and continued work on schematics
    [SwitchBackplane.sch]
2021-08-27 Clean up git structure, move interface designs into their own folder
    Clean up the mess that's been building up so far.
    [PhoneInterface-B_CrtYd.gbr, PhoneInterface-B_Cu.gbr, PhoneInterface-B_Mask.gbr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]
2021-08-27 Continue work on the backplane schematic and add Pi Pico footprint files
    [SwitchBackplane.sch]
2021-08-27 Fix library table entries
    [SwitchBackplane.sch]
2021-08-28 Update notes and progress more on schematic
    [SwitchBackplane.sch]
2021-08-29 Continue work on schematic
    [SwitchBackplane.sch]
2021-08-30 Clarify pin counts and fix notes error, continue work on schematic
    [SwitchBackplane.sch]
2021-08-31 More work on schematics
    [SwitchBackplane.sch]
2021-08-31 Further work on schematic, rearranged some things on IO expander ICs
    [SwitchBackplane.sch]
2021-09-01 Start to finish up schematic, add PDF of current schematic revision
    [SwitchBackplane.sch]
2021-09-01 Fixed a few small issues, annotated schematic, cleaned up annotations, fixed issue with switch ICs
    The annotations were a mess, cleaned them all up. Also modified some components so the ERC would stop complaining. Fixed the issue with forgetting to connect switch IC enable, and finally made all the ICs Ux.
    [SwitchBackplane.sch]
2021-09-01 Associate footprints with parts, other tweaks
    [SwitchBackplane.sch]
2021-09-01 Tweaks to schematic, associate all footprints
    [SwitchBackplane.sch]
2021-09-01 Update footprint libraries, fixed broken footprint association
    [SwitchBackplane.sch]
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2021-09-01 Add mounting holes to schematic
    [SwitchBackplane.sch]
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2022-02-13 Adapted and updated schematics and PCB design.
    Converted schematics and board layouts to new file, as well as move design from one backplane to multiple modules.
    [PhoneInterface.kicad_pcb, PhoneInterface.kicad_sch, PhoneInterface.sch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]
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2022-04-03 Redoing layout
    Redoing layout to fix the issues related to the in/mm switch at some point and me not noticing.
    [ToneEncoderDecoder.kicad_pcb, ToneEncoderDecoder_Old.kicad_pcb]
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2022-04-04 Finish routing (for the first time)
    Okay, unrouted nets says 0. However, this could probably use some cleanup.
    [ToneEncoderDecoder.kicad_pcb]
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
